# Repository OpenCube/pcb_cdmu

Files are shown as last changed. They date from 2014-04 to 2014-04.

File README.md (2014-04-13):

OpenCube CDMU
=============

The OpenCube Command and Data Management Unit (CDMU) is an embedded Linux computer. It coordinates the various functions of the spacecraft. In particular, it peforms the following tasks:

 * Telemetry pre-processing and encoding
 * Telecommand decoding
 * Communication session management
 * Resource allocation
 * Fault mitigation

In its current version, it consists of a BeagleBone Black board mounted on a custom circuit board with CAN bus transceivers. In the future, the board will also include a latch-up protection circuit, external memory (FRAM) and an external watchdog circuit. Eventually, the BeagleBone will be replaced with an AM3359 processor and its support components.

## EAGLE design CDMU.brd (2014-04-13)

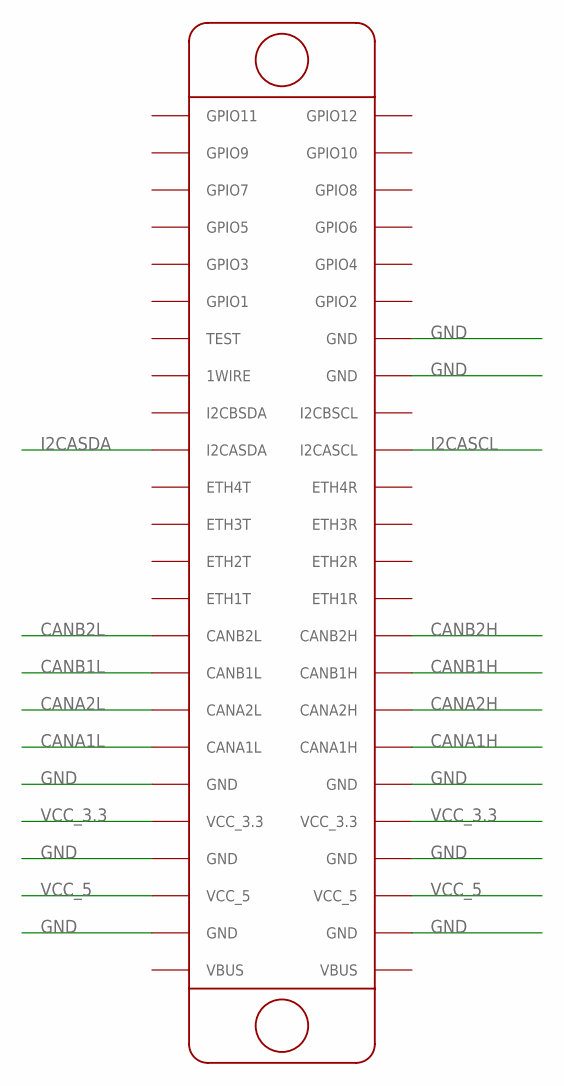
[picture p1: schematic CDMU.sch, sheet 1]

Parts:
U$1: CUBESAT_PCB

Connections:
CANA1H: U$1.CANA1H; also elsewhere on the board
CANA1L: U$1.CANA1L; also elsewhere on the board
CANA2H: U$1.CANA2H; also elsewhere on the board
CANA2L: U$1.CANA2L; also elsewhere on the board
CANB1H: U$1.CANB1H; also elsewhere on the board
CANB1L: U$1.CANB1L; also elsewhere on the board
CANB2H: U$1.CANB2H; also elsewhere on the board
CANB2L: U$1.CANB2L; also elsewhere on the board
GND: U$1.GND@5 (GND), U$1.GND@6 (GND), U$1.GND@7 (GND), U$1.GND@8 (GND), U$1.GND@9 (GND), U$1.GND@10 (GND), U$1.GND@11 (GND), U$1.GND@12 (GND); also elsewhere on the board
I2CASCL: U$1.I2CASCL; also elsewhere on the board
I2CASDA: U$1.I2CASDA; also elsewhere on the board
VCC_3.3: U$1.VCC_3.3@1 (VCC_3.3), U$1.VCC_3.3@2 (VCC_3.3); also elsewhere on the board
VCC_5: U$1.VCC_5@1 (VCC_5), U$1.VCC_5@2 (VCC_5); also elsewhere on the board

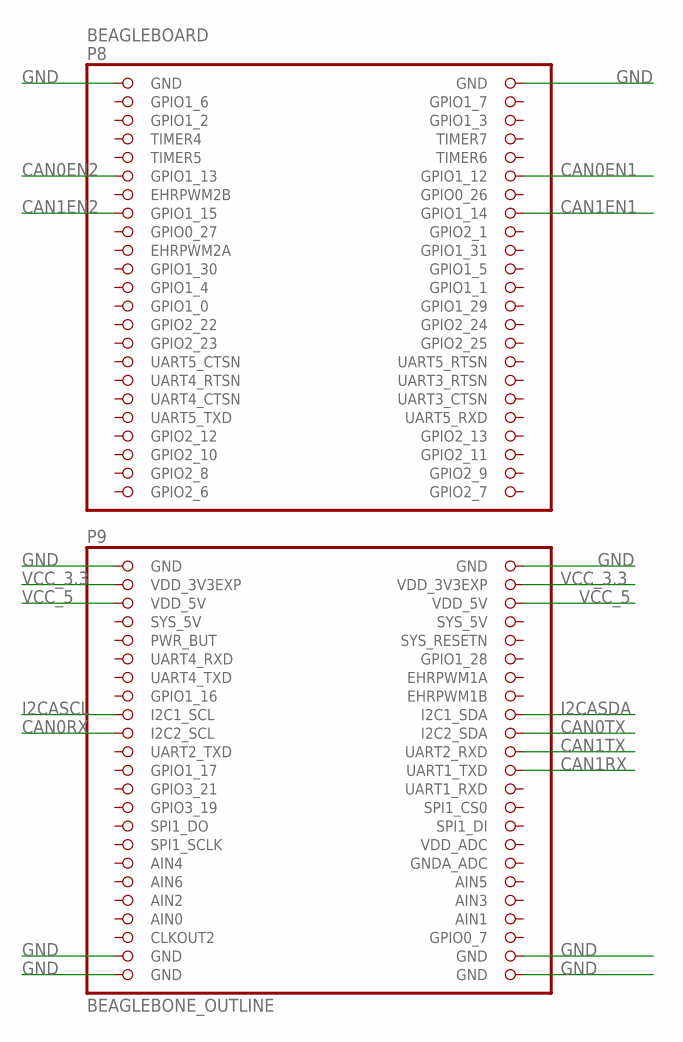
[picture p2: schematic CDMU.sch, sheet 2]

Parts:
BEAGLEBOARD: BEAGLEBONE_OUTLINE; BEAGLEBONE_SHIELD

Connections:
AIN0: BEAGLEBOARD.85 (AIN0)
CAN0EN1: BEAGLEBOARD.12 (GPIO1_12); also elsewhere on the board
CAN0EN2: BEAGLEBOARD.11 (GPIO1_13); also elsewhere on the board
CAN0RX: BEAGLEBOARD.65 (I2C2_SCL); also elsewhere on the board
CAN0TX: BEAGLEBOARD.66 (I2C2_SDA); also elsewhere on the board
CAN1EN1: BEAGLEBOARD.16 (GPIO1_14); also elsewhere on the board
CAN1EN2: BEAGLEBOARD.15 (GPIO1_15); also elsewhere on the board
CAN1RX: BEAGLEBOARD.70 (UART1_TXD); also elsewhere on the board
CAN1TX: BEAGLEBOARD.68 (UART2_RXD); also elsewhere on the board
GND: BEAGLEBOARD.1 (GND), BEAGLEBOARD.2 (GND), BEAGLEBOARD.47 (GND), BEAGLEBOARD.48 (GND), BEAGLEBOARD.89 (GND), BEAGLEBOARD.90 (GND), BEAGLEBOARD.91 (GND), BEAGLEBOARD.92 (GND); also elsewhere on the board
I2CASCL: BEAGLEBOARD.63 (I2C1_SCL); also elsewhere on the board
I2CASDA: BEAGLEBOARD.64 (I2C1_SDA); also elsewhere on the board
SYS_5V: BEAGLEBOARD.53 (SYS_5V)
VCC_3.3: BEAGLEBOARD.49 (VDD_3V3EXP), BEAGLEBOARD.50 (VDD_3V3EXP); also elsewhere on the board
VCC_5: BEAGLEBOARD.51 (VDD_5V), BEAGLEBOARD.52 (VDD_5V); also elsewhere on the board

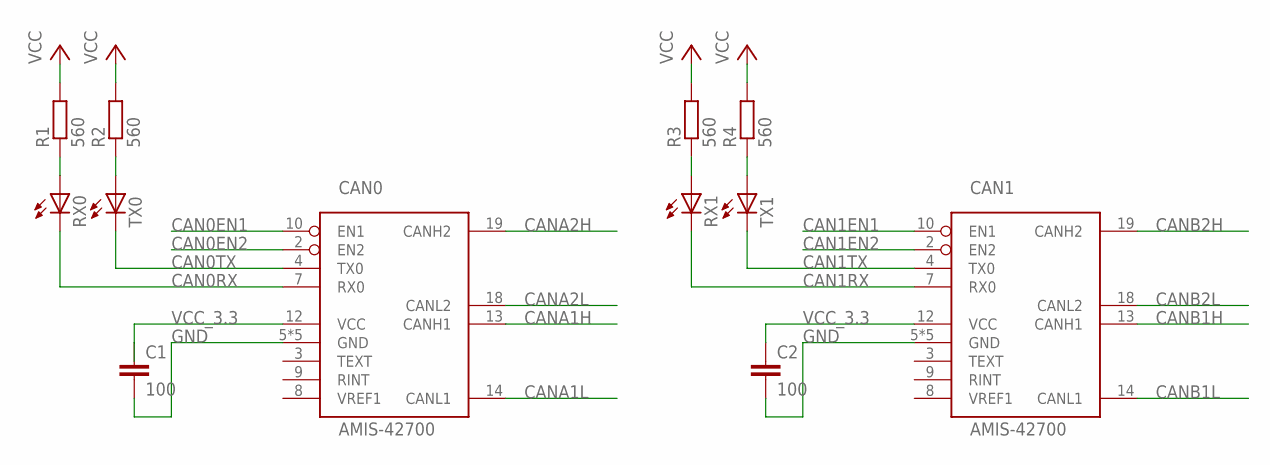
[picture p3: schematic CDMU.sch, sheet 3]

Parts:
C1, C2: 100; C0805
CAN0, CAN1: AMIS-42700; SOIC20
R1, R2, R3, R4: 560; R0805
RX0, RX1: LED3MM
TX0, TX1: LED3MM

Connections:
CAN0EN1: CAN0.10 (EN1); also elsewhere on the board
CAN0EN2: CAN0.2 (EN2); also elsewhere on the board
CAN0RX: CAN0.7 (RX0), RX0.K (C); also elsewhere on the board
CAN0TX: CAN0.4 (TX0), TX0.K (C); also elsewhere on the board
CAN1EN1: CAN1.10 (EN1); also elsewhere on the board
CAN1EN2: CAN1.2 (EN2); also elsewhere on the board
CAN1RX: CAN1.7 (RX0), RX1.K (C); also elsewhere on the board
CAN1TX: CAN1.4 (TX0), TX1.K (C); also elsewhere on the board
CANA1H: CAN0.13 (CANH1); also elsewhere on the board
CANA1L: CAN0.14 (CANL1); also elsewhere on the board
CANA2H: CAN0.19 (CANH2); also elsewhere on the board
CANA2L: CAN0.18 (CANL2); also elsewhere on the board
CANB1H: CAN1.13 (CANH1); also elsewhere on the board
CANB1L: CAN1.14 (CANL1); also elsewhere on the board
CANB2H: CAN1.19 (CANH2); also elsewhere on the board
CANB2L: CAN1.18 (CANL2); also elsewhere on the board
GND: C1.2, C2.2, CAN0.5 (GND), CAN0.6 (GND), CAN0.15 (GND), CAN0.16 (GND), CAN0.17 (GND), CAN1.5 (GND), CAN1.6 (GND), CAN1.15 (GND), CAN1.16 (GND), CAN1.17 (GND); also elsewhere on the board
unnamed: R1.1, RX0.A
unnamed: R2.1, TX0.A
unnamed: R3.1, RX1.A
unnamed: R4.1, TX1.A
VCC_3.3: C1.1, C2.1, CAN0.12 (VCC), CAN1.12 (VCC), R1.2, R2.2, R3.2, R4.2; also elsewhere on the board

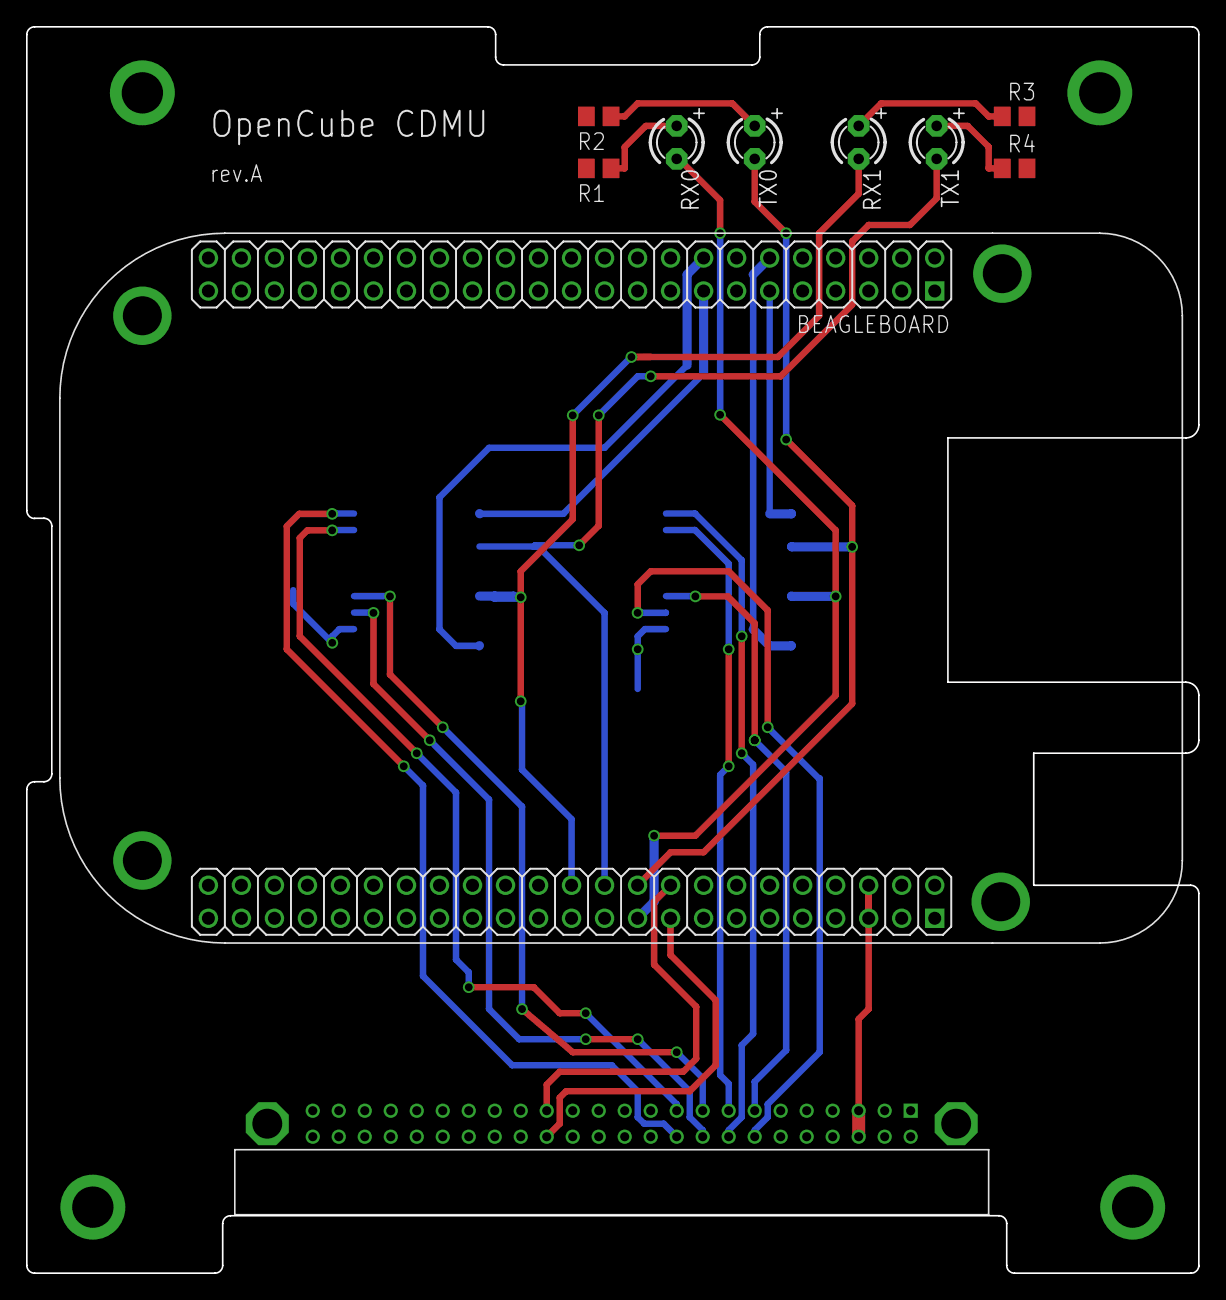
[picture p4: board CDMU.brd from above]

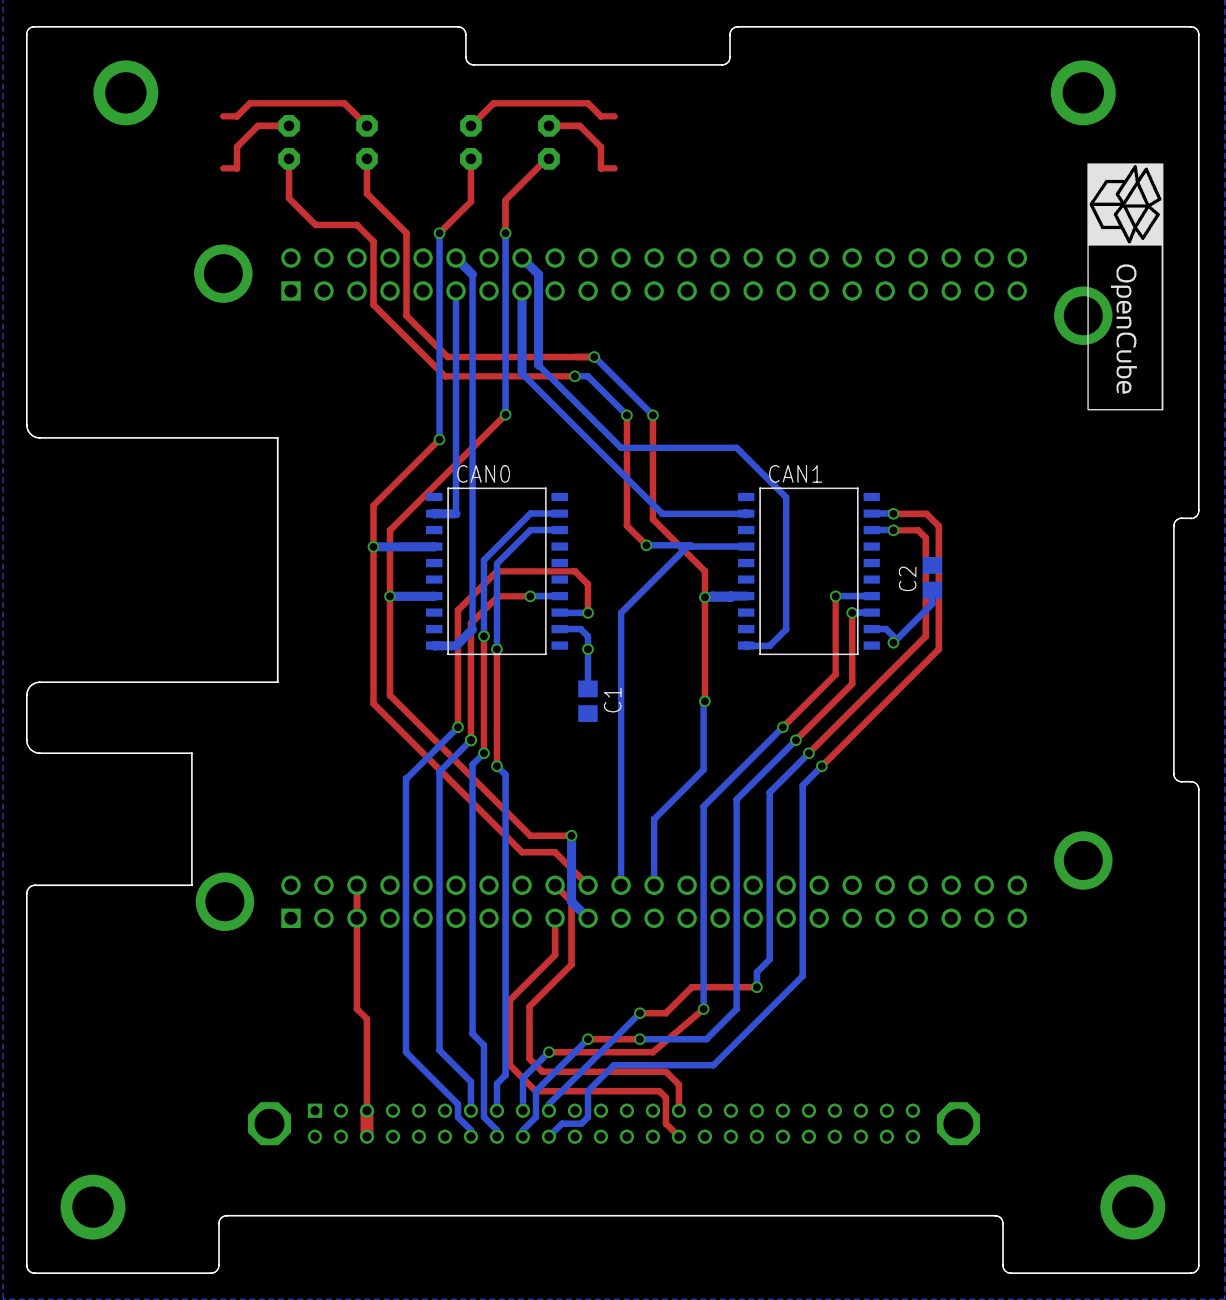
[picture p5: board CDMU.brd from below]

Board: 4 copper layers, 90.2 x 95.9 mm, 14 parts (4 on the bottom side), 25 nets.
